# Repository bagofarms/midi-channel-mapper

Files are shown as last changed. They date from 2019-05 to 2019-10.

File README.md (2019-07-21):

# MIDI Channel Mapper

The MIDI Channel Mapper allows you to map any input MIDI channel to any output MIDI channel with a user-friendly interface.  Multiple input channels can map to the same output channel, and there are preset modes for directing all input channels to a single output channel and disabling all output.

## Bill of Materials

| Qty | Part | Label |
|-----|---|---|
| 1 | SPST Switch | PWR_SW |
| 1 | DPST Switch | MIDI_DISABLE_SW |
| 1 | 4.7kohm Resistor | R1 |
| 4 | 220ohm Resistor | R2, R3, R4, R5 |
| 1 | 1N914 Diode | D1 |
| 1 | 6N138 Opto-isolator | U1 |
| 1 | PJ-002A Barrel Jack Power Connector | DC1 |
| 1 | HD16K33 7-Segment Display and Backpack | DISP |
| 2 | 10kohm Potentiometer (ALPS RK203) | POT_IN, POT_OUT |
| 1 | SPST Pushbutton | SAVE_BTN |
| 2 | SDS-50J Female MIDI Connector | MIDI_IN, MIDI_OUT |
| 1 | Arduino Nano (or clone) | NANO_1, NANO_2 |

## Aruino Library Dependencies

* MIDI.h
* Wire.h
* Adafruit_GFX.h
* Adafruit_LEDBackpack.h

## Contributors

* [Jacob Bates](https://github.com/bagofarms)
* [Zach Berry](https://github.com/zachberry)
* [Shea Silverman](https://github.com/SheaSilverman)

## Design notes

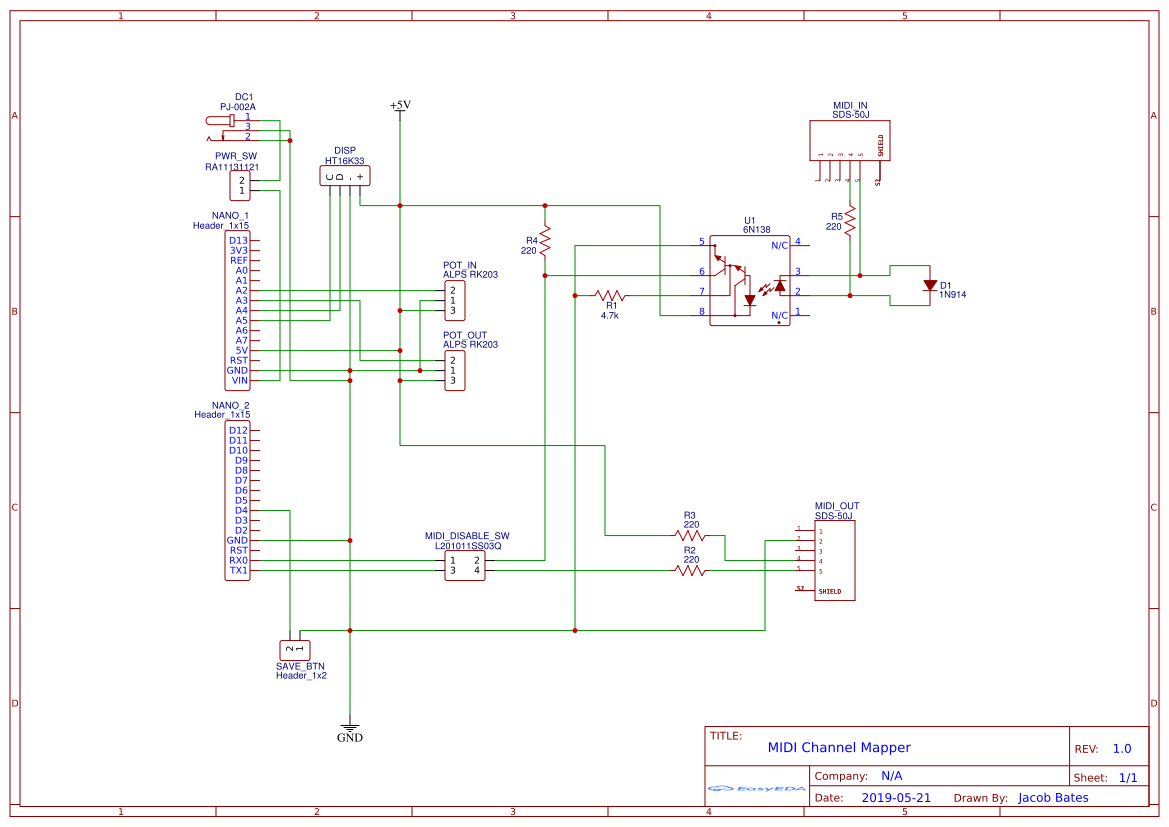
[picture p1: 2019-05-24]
board/schematic.png

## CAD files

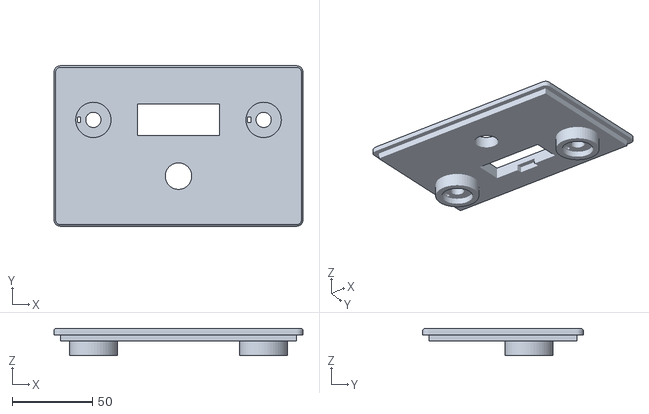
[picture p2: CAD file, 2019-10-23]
box/midi_chanel_mapper_lid.stl
155.0 x 100.0 x 17.0

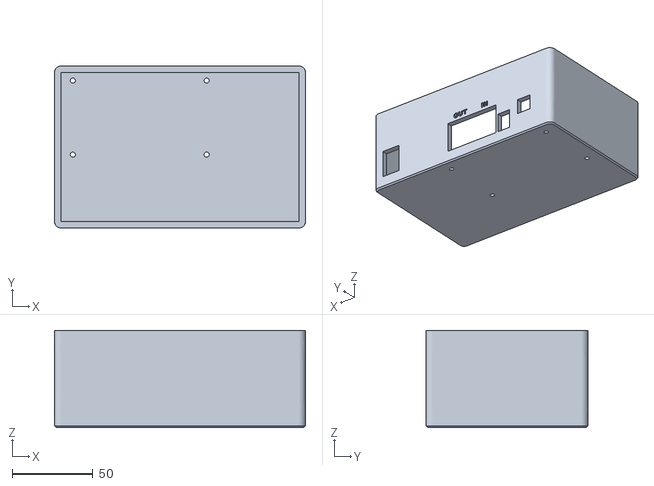
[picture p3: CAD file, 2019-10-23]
box/midi_channel_mapper_box.stl
155.0 x 100.0 x 60.0

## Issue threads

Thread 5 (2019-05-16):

Change channel instantly with button held down

zachberry, 2019-05-16:
Thinking if you hold the 'save' button down then turning the right dial would switch the output channel on change.

bagofarms, 2019-05-18:
Turns out this is an emergent feature, and already works as expected!

Closed 2019-05-18.

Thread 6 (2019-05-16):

Save mappings between power cycles (and allow reset)

zachberry, 2019-05-16:
If we can I'd like to save the mappings to EEPROM. Then, maybe holding the save button for 5 seconds or something could reset the mappings to default.

bagofarms, 2019-05-16:
This should help:  https://www.arduino.cc/en/Reference/EEPROM

bagofarms, 2019-05-18:
Still need to implement a reset system.

bagofarms, 2019-05-19:
Resetting is now allowed by holding down the save button while resetting

Closed 2019-05-19.

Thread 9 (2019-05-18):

Disable all outputs if save button is pressed for 5 seconds during power on.

bagofarms, 2019-05-18:
In that case the default is all channels will always be routed to "--", or 17.

bagofarms, 2019-05-19:
The display should show ---- instead of 0000 when this has happened.

Closed 2019-05-19.

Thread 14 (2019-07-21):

Circuit board quality of life improvements

bagofarms, 2019-07-21:
- Move headers farther away from mounting holes so that the traces can have plenty of clearance.
- Label each header pin
- Add part numbers for all parts
- Label all pins on Arduino Nano
- Increase clearance between traces to make visual inspection easier.

Closed 2019-07-21.

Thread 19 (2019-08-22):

Make a version of the board with all ports on one side, including peripherals

bagofarms, 2019-08-22:
Move the peripheral ports to the same side of the board as the MIDI, power, and USB.  Also, add another set of mounting holes for screw terminals so that the end user can choose how to connect peripherals

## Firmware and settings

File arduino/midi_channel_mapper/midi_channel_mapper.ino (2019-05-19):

#include <EEPROM.h>
#include <MIDI.h>
#include <Wire.h> // Enable this line if using Arduino Uno, Mega, etc.
#include <Adafruit_GFX.h>
#include "Adafruit_LEDBackpack.h"

Adafruit_7segment matrix = Adafruit_7segment();

#define SOFTWARE_VERSION 1

// Number of seconds to hold down save button on power up to enter
// "all outputs disabled" mode
#define DISABLE_OUTPUTS_DELAY 4

// Matrix raw display values
#define MATRIX_BLANK 0B000000000
#define MATRIX_DASH 0B001000000

// Potentiometer inputs
#define MAX_POT_VALUE 1024
#define TOTAL_POT_STEPS 17
#define CHAN_IN_POT 2
#define CHAN_OUT_POT 3
float EMA_a = 0.6;      //initialization of EMA alpha
int EMA_S_in = 0;       //initialization of EMA S for input channel
int EMA_S_out = 0;      //initialization of EMA S for output channel

#define DEBUG true

MIDI_CREATE_DEFAULT_INSTANCE();

byte in_pot_channel = 0;
byte out_pot_channel = 0;
byte last_in_pot_channel = 0;
byte last_out_pot_channel = 0;
bool is_out_pot_dirty = false;

// Array to hold inputs and outputs.  Index is input channel, value is output channel.
// 0 = No output, 1 = Midi Channel 1, ..., 16 = Midi Channel 16
byte channel_map[17] = {MIDI_CHANNEL_OFF, 1, 2, 3, 4, 5, 6, 7, 8, 9, 10, 11, 12, 13, 14, 15, 16};

// Array to keep track of which channels are active. We use this information to display
// a dot in the LED display next to the input channel (so the user can see visually
// which channels are getting messages)
bool active_map[17] = {false, false, false, false, false, false, false, false, false, false, false, false, false, false, false, false, false};

// EEPROM Addresses
#define VERSION_ADDR 0 // value of 1 if memory has been initialized
#define CHANNEL_MAP_ADDR 1 // 1 - 17

// Stuff that only runs every so often
#define LOOP_DELAY 500
int loop_ticks = 0;

// Button
#define BUTTON_PIN 4
int button_state;

void setup()
{
  // Save Button
  pinMode(BUTTON_PIN, INPUT_PULLUP);
  button_state = digitalRead(BUTTON_PIN);
  
  // Load saved data from EEPROM if it has been initialized
  byte versionNum = EEPROM.read(VERSION_ADDR);
  if ((versionNum == SOFTWARE_VERSION) && (button_state == HIGH))
  {
    EEPROM.get(CHANNEL_MAP_ADDR, channel_map);
  }
  // Otherwise, initialize the EEPROM
  else
  {
    EEPROM.put(CHANNEL_MAP_ADDR, channel_map);

    // Set the initialized flag
    EEPROM.write(VERSION_ADDR, 1);
  }

  // Init display
  matrix.begin(0x70);
  matrix.drawColon(false);
  matrix.writeDigitRaw(0, MATRIX_BLANK);
  matrix.writeDigitRaw(1, MATRIX_BLANK);
  matrix.writeDigitRaw(3, MATRIX_BLANK);
  matrix.writeDigitRaw(4, MATRIX_BLANK);
  matrix.writeDisplay();

  int counter = 0;
  while(button_state == LOW)
  {
    if(counter > (DISABLE_OUTPUTS_DELAY * 10))
    {
      matrix.writeDigitRaw(0, MATRIX_DASH);
      matrix.writeDigitRaw(1, MATRIX_DASH);
      matrix.writeDigitRaw(3, MATRIX_DASH);
      matrix.writeDigitRaw(4, MATRIX_DASH);
      matrix.writeDisplay();
    }
    else
    {
      counter++;
    }
    button_state = digitalRead(BUTTON_PIN);
    delay(100);
  }

  // If the user held the button long enough, disable all channels
  if(counter > (DISABLE_OUTPUTS_DELAY * 10))
  {
    disableAllChannels();
  }
  
  // Display Zeroes
  
  matrix.setBrightness(1);
  matrix.writeDigitNum(0, 0, false);
  matrix.writeDigitNum(1, 0, false);
  matrix.writeDigitNum(3, 0, false);
  matrix.writeDigitNum(4, 0, false);
  matrix.writeDisplay();
  delay(1000);

  MIDI.setHandleNoteOn(handleNoteOn);
  MIDI.setHandleNoteOff(handleNoteOff);
  MIDI.setHandleControlChange(handleControlChange);
  MIDI.setHandleProgramChange(handleProgramChange);
  MIDI.setHandleAfterTouchPoly(handleAfterTouchPolyPressure);
  MIDI.setHandleAfterTouchChannel(handleAfterTouchChannelPressure);
  MIDI.setHandlePitchBend(handlePitchBend);
  MIDI.setHandleTimeCodeQuarterFrame(handleTimeCodeQuarterFrame);
  MIDI.setHandleSongPosition(handleSongPosition);
  MIDI.setHandleSongSelect(handleSongSelect);
  MIDI.setHandleTuneRequest(handleTuneRequest);
  MIDI.setHandleClock(handleClock);
  MIDI.setHandleStart(handleStart);
  MIDI.setHandleContinue(handleContinue);
  MIDI.setHandleStop(handleStop);
  MIDI.setHandleActiveSensing(handleActiveSensing);
  MIDI.setHandleSystemReset(handleSystemReset);
  // (SysEx messages are not supported)

  MIDI.begin(MIDI_CHANNEL_OMNI);

  MIDI.turnThruOff();

  getPotInputs();
  displayChannels();
}

void loop()
{
  MIDI.read();

  button_state = digitalRead(BUTTON_PIN);
  if (button_state == LOW)
  {
    updateChannels();
  }

  // Run the pot inputs and display channels every 100 loops
  if (++loop_ticks == LOOP_DELAY)
  {
    displayChannels();
    getPotInputs();
    resetActiveStateForAllChannels();

    loop_ticks = 0;
  }
}

byte getOutChannel(byte in_channel)
{
  // The OMNI channel output takes first prioirty. If it's set
  // then send ALL messages to that channel!
  if (isOMNIMode())
  {
    return channel_map[MIDI_CHANNEL_OMNI];
  }

  return channel_map[in_channel];
}

bool isOMNIMode()
{
  return channel_map[MIDI_CHANNEL_OMNI] != MIDI_CHANNEL_OFF;
}

// -------------------------------------------
// MIDI Handlers:
// -------------------------------------------

void handleProgramChange(byte channel, byte number)
{
  markChannelAsActive(channel);
  MIDI.sendProgramChange(number, getOutChannel(channel));
}

void handleNoteOn(byte channel, byte note, byte velocity)
{
  markChannelAsActive(channel);
  MIDI.sendNoteOn(note, velocity, getOutChannel(channel));
}

void handleNoteOff(byte channel, byte note, byte velocity)
{
  markChannelAsActive(channel);
  MIDI.sendNoteOff(note, velocity, getOutChannel(channel));
}

void handlePitchBend(byte channel, int bend)
{
  markChannelAsActive(channel);
  MIDI.sendPitchBend(bend, getOutChannel(channel));
}

void handleControlChange(byte channel, byte number, byte value)
{
  markChannelAsActive(channel);
  MIDI.sendControlChange(number, value, getOutChannel(channel));
}

void handleAfterTouchPolyPressure(byte channel, byte note, byte pressure)
{
  markChannelAsActive(channel);
  MIDI.sendAfterTouch(note, pressure, getOutChannel(channel));
}

void handleAfterTouchChannelPressure(byte channel, byte pressure)
{
  markChannelAsActive(channel);
  MIDI.sendAfterTouch(pressure, getOutChannel(channel));
}

void handleTimeCodeQuarterFrame(byte data)
{
  MIDI.sendTimeCodeQuarterFrame(data);
}

void handleSongPosition(unsigned beats)
{
  MIDI.sendSongPosition(beats);
}

void handleSongSelect(byte songnumber)
{
  MIDI.sendSongSelect(songnumber);
}

void handleTuneRequest()
{
  MIDI.sendTuneRequest();
}

// Real time messages (Messages that don't specify channels)
// (These messages don't have their own sendX method, instead we must use a
// lower-level send method from the library):
void handleClock()
{
  MIDI.sendRealTime(midi::Clock);
}

void handleStart()
{
  MIDI.sendRealTime(midi::Start);
}

void handleContinue()
{
  MIDI.sendRealTime(midi::Continue);
}

void handleStop()
{
  MIDI.sendRealTime(midi::Stop);
}

void handleActiveSensing()
{
  MIDI.sendRealTime(midi::ActiveSensing);
}

void handleSystemReset()
{
  MIDI.sendRealTime(midi::SystemReset);
}

// -------------------------------------------
// Manual input methods:
// -------------------------------------------

void getPotInputs()
{
  // In pot should read OMNI (0), then 1 to 16
  in_pot_channel = normalizePotInput(emaSmooth(analogRead(CHAN_IN_POT), &EMA_S_in), true);
  // Out pot should read OFF, then 1 to 16
  out_pot_channel = normalizePotInput(emaSmooth(analogRead(CHAN_OUT_POT), &EMA_S_out), false);

  // If the in pot has changed then reset the out pot dirty state
  // (in other words, any un-saved out pot value is discarded)
  if (is_out_pot_dirty && in_pot_channel != last_in_pot_channel)
  {
    is_out_pot_dirty = false;
  }
  // If the out pot has changed we set the dirty flag, meaning the
  // user has rotated the pot and is wanting to set the out channel
  else if (!is_out_pot_dirty && out_pot_channel != last_out_pot_channel)
  {
    is_out_pot_dirty = true;
  }
  // If the out pot has changed back to the currently set value
  // of the input, the out pot is not dirty anymore
  else if (is_out_pot_dirty && out_pot_channel == channel_map[in_pot_channel])
  {
    is_out_pot_dirty = false;
  }

  last_in_pot_channel = in_pot_channel;
  last_out_pot_channel = out_pot_channel;
}

int normalizePotInput(float rawIn, bool zeroIndex)
{
  rawIn = rawIn / MAX_POT_VALUE;
  rawIn = rawIn * (TOTAL_POT_STEPS - 1);
  int out = (int)(rawIn + 0.5f);

  // Putting this here because the channel input starts at zero,
  // but the channel output starts at 1 and goes to "--"
  if (!zeroIndex)
  {
    out += 1;
  }
  return out;
}

int emaSmooth(int sensorValue, int* EMA_S)
{
  *EMA_S = (EMA_a*sensorValue) + ((1-EMA_a) * (*EMA_S));
  return *EMA_S;
}

// -------------------------------------------
// Display methods:
// -------------------------------------------

void displayChannels()
{
  bool isOmni = isOMNIMode();

  // Display the colons if in omni mode to indicate locked outputs
  matrix.drawColon(isOmni);
  
  // We display the left dot if we got a MIDI message on that channel:
  displayLeft(in_pot_channel, isChannelActive(in_pot_channel));

  // If the out pot has been rotated (is_out_pot_dirty=true) then we display
  // the current actual out pot value along with the 'dirty' dot.
  // If we're in omni mode, ignore this case.
  if (is_out_pot_dirty && (!isOmni || in_pot_channel == 0))
  {
    displayRight(out_pot_channel, true);
  }
  // Otherwise, show what the current mapping is for the given in pot channel.
  else
  {
    displayRight(getOutChannel(in_pot_channel), false);
  }
}

void displayLeft(byte val, bool dot)
{
  int leftDigit = val / 10;
  if (leftDigit == 0)
  {
    matrix.writeDigitRaw(0, MATRIX_BLANK);
  }
  else
  {
    matrix.writeDigitNum(0, (val / 10), false);
  }
  matrix.writeDigitNum(1, val % 10, dot);
  matrix.writeDisplay();
}

// NOTE: MIDI_CHANNEL_OFF is actually 17, but we want to display that
// on the LCD as "--".
void displayRight(int val, bool dot)
{
  if (val == MIDI_CHANNEL_OFF)
  {
    // Display "--"
    matrix.writeDigitRaw(3, MATRIX_DASH);
    matrix.writeDigitRaw(4, MATRIX_DASH);
  }
  else
  {
    int leftDigit = val / 10;
    if (leftDigit == 0)
    {
      matrix.writeDigitRaw(3, MATRIX_BLANK);
    }
    else
    {
      matrix.writeDigitNum(3, (val / 10), false);
    }
    matrix.writeDigitNum(4, val % 10, dot);
  }
  
  matrix.writeDisplay();
}

void updateChannels()
{
  // If we're in omni mode, ignore all changes except for 0
  if ((!isOMNIMode() || in_pot_channel == 0) && is_out_pot_dirty)
  {
    channel_map[in_pot_channel] = out_pot_channel;
    EEPROM.write(CHANNEL_MAP_ADDR + in_pot_channel, out_pot_channel);
    
    is_out_pot_dirty = false;
  }
  
}

void disableAllChannels()
{
  channel_map[MIDI_CHANNEL_OMNI] = MIDI_CHANNEL_OFF;
  channel_map[1] = MIDI_CHANNEL_OFF;
  channel_map[2] = MIDI_CHANNEL_OFF;
  channel_map[3] = MIDI_CHANNEL_OFF;
  channel_map[4] = MIDI_CHANNEL_OFF;
  channel_map[5] = MIDI_CHANNEL_OFF;
  channel_map[6] = MIDI_CHANNEL_OFF;
  channel_map[7] = MIDI_CHANNEL_OFF;
  channel_map[8] = MIDI_CHANNEL_OFF;
  channel_map[9] = MIDI_CHANNEL_OFF;
  channel_map[10] = MIDI_CHANNEL_OFF;
  channel_map[11] = MIDI_CHANNEL_OFF;
  channel_map[12] = MIDI_CHANNEL_OFF;
  channel_map[13] = MIDI_CHANNEL_OFF;
  channel_map[14] = MIDI_CHANNEL_OFF;
  channel_map[15] = MIDI_CHANNEL_OFF;
  channel_map[16] = MIDI_CHANNEL_OFF;
  EEPROM.put(CHANNEL_MAP_ADDR, channel_map);
}

void markChannelAsActive(byte channel)
{
  active_map[MIDI_CHANNEL_OMNI] = true;
  
  active_map[channel] = true;
}

bool isChannelActive(byte channel)
{
  return active_map[channel];
}

void resetActiveStateForAllChannels()
{
  active_map[MIDI_CHANNEL_OMNI] = false;
  active_map[1] = false;
  active_map[2] = false;
  active_map[3] = false;
  active_map[4] = false;
  active_map[5] = false;
  active_map[6] = false;
  active_map[7] = false;
  active_map[8] = false;
  active_map[9] = false;
  active_map[10] = false;
  active_map[11] = false;
  active_map[12] = false;
  active_map[13] = false;
  active_map[14] = false;
  active_map[15] = false;
  active_map[16] = false;
}

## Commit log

2018-05-08 Changed back to normal serial to use with an Arduino Nano clone. Works as passthrough with debug display on OLED.
2018-05-13 Added program change and passthrough. Added pitch bend. Some reorganizing.
2019-05-12 Added in button code
2019-05-12 Change to using segmented led display for speed and memory benefits
2019-05-18 Add constants for led characters, implement dashes
2019-05-18 Fix in channel to start at 0
    [midi_channel_mapper.ino]
2019-05-19 Add reset functionality. Fixes #6
    [midi_channel_mapper.ino]
2019-05-19 Disable outputs when button pressed for amount of time during power on. Fixes #9
    [midi_channel_mapper.ino]
2019-05-24 Add board files and restructure.
    [Gerber_BoardOutline.GKO, Gerber_BottomLayer.GBL, Gerber_BottomSolderMaskLayer.GBS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]
2019-07-21 Update SVG and Gerber files to Revision 2. Fixes #14
    [Gerber_BoardOutline.GKO, Gerber_BottomLayer.GBL, Gerber_BottomSolderMaskLayer.GBS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]
2019-10-23 Redesign board and add molex connections for peripherals
    [Gerber_BottomLayer.GBL, Gerber_BottomSolderMaskLayer.GBS, Gerber_Drill_NPTH.DRL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]
2019-10-23 Upload STLs for box
    [midi_chanel_mapper_lid.stl, midi_channel_mapper_box.stl]
